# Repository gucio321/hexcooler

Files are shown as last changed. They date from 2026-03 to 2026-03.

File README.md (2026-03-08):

# Intro
HexCooler is a laptop cooling stand project designed with a hexagonal pattern.

# BOM
> [!note]
> The BOM is work in progress. It is possible that some materials are missing right now.

> [!important]
> I assume you have basic knowledge about 3D printing as well as access to a 3D printer.
> Also, I assume you have basic knowledge about soldering and you have access to a soldering setup.

> [!tip]
> I don't give you links as I assume you can find the best offer yourself :smile:

> [!tip]
> I did most purchases in PLN, so USD prices are approximate.

| Item | Quantity | Price [PLN] | Price [USD] | Notes |
|---|---|---|---|---|
| Filaments (PLA)  | 2 * 1 kg (one black and one red - pick whatever colors you want) | 85 | 24 |  |
| Be Quiet! Pure Wings 3 140mm 3-Pin black | 1 | 50 | 14 |  |
| Hex Cooler V1 PCB on [JLCPCB](https://jlcpcb.com/) (see [project file](./hexcooler_v1.epro)) | 2 assembled + 3 printed boards | 73.20 | 20 | This is what I paid for USD in my bank. In reality, it was a bit cheaper on JLCPCB (as some of those USD left on my currency account) |
| **Total** |  | 208.20 | 58 |  |

> [!note]
> I also used some universal pins to connect my fan to the PCB. You can alternatively use goldpins or (not recommended) cut the plug and solder the fan wires directly to the PCB.

> [!note]
> As this is V1 I ordered only 2 assembled boards from JLCPCB. If you are going to build multiple coolers, it is theoretically possible to cut costs by ordering more assembled boards.
> Also, if you have advanced soldering skills, you can order unassembled boards + components (much cheaper) and solder them yourself.
> Also I didn't print all the filament I bought - you can save some money there.

# How to build

1. Chose a PCB version (tl;dr: [v2](./hexcooler_v2.epro) is recommended) see [#PCB-versions]
1. Order all the parts from the BOM. Note that delivery time especially for PCBs may be long.
2. Install FreeCAD
3. Download this repository
4. Open `hexcooler.fcstd` in FreeCAD
5. Click on `VarSet` and adjust whatever parameters you want (e.g. fan holder size, hex dimensions, e.t.c.)
6. Export each individual part
   (PROTIP: If your printer is too small to print the whole part at once, you can set NX/NY to e.g. half, and print twice,
   but be careful to verify before printing - some frame parts are 1 tile wider so printing them twice will not work with
   printing the grid twice - you know what I mean, just count tiles and you'll see what I mean :smile:).
   One more protip: I recommend printing a small prototype first (e.g. with nx=1, ny=1) and check if junctions fit well (they should not be too loose or too ight - check JunctionTolerance var).
7. Print all the parts
8. Assemble the parts together (you can use some glue if you need but I didn't use any and it works for me)
9. Its done! GG!

## PCB versions

At this point, there are two variants of the PCB.
The first one (v1) is a really minimalistic design with only one fan connector and no mounting holes (what makes it really uncomfortable to use).
If you want this version, you should design your own BoardHandler part (as one in the project is really bad and because v2 exists I'm not going to fix it).
If you really want to use the project design, take a look at models from commit 1aaabbce1ec494832992ce61475a56b12ce3519e

V2 is a much better design imao. It includes 4 12V fan connectors and in addition 3 5V connectors for e.g. some leds (not tested yet). It also includes mounting holes which makes it that plugging the
USB cable is not a nightmare anymore. I highly recommend using this version, especially that it is not more expensive than v1 (as the price of PCB on JLCPCB is mostly determined by assembly costs and not size of the PCB).

# Status
WIP :smile:

**04.11.2025** The first project iteration has just been printed. It has some minor issues (e.g. one missing junction) which however has already been fixed.
I also experienced a skill issue (while exporting the bottom part I didn't export mirrors)
**18.01.2026** The project has been printed almost entirely and is under use. It is missing some minor parts (e.g. the stand - comming soon) but geneerally looks good and is usable.

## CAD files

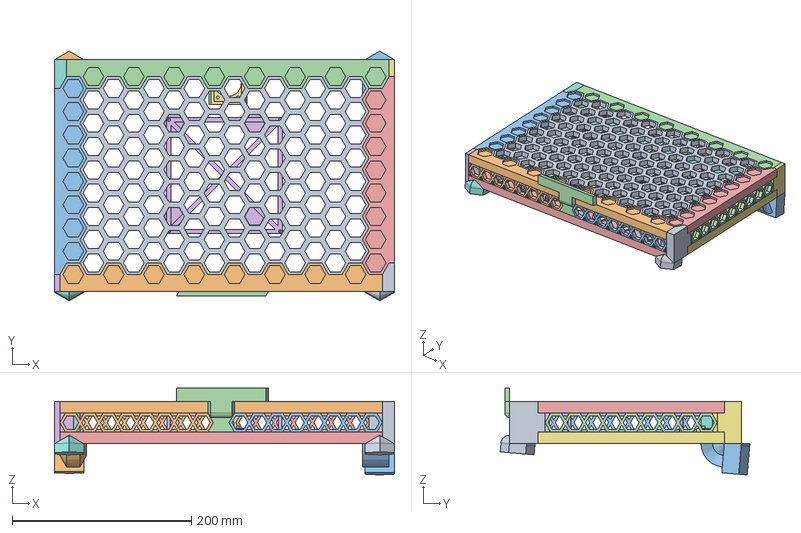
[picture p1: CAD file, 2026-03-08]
hexcooler.FCStd
379.8 x 278.8 x 97.1 mm
Grid
FrameBot
FrameLeft
FrameTop
FrameRight
StemLB
StemRT
StemLT
StemRB
InteriorMaskFrontLeft
InteriorMaskFrontRight
FrontPanel
DFrameBot (Mirror #1)
DGrid (Mirror #2)
DFrameRight (Mirror #3)
DFrameTop (Mirror #4)
DFrameLeft (Mirror #5)
InteriorMaskBackLeft (Mirror #6)
InteriorSideLeft
InteriorSideRight (Mirror #8)
InteriorMaskBackRight (Mirror #8)
FanHolder
BoardHolder
StandLB
StandRB
StandLT
StandRT

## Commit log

2025-10-26 parametrize junction
    [top.FCStd]
2025-10-26 rework to use MultipleTransform instead of drafts
    [top.FCStd]
2025-10-27 top: fix tip; add Internal section in VarSet
    [top.FCStd]
2025-10-27 top: add mjunction on left side
    [top.FCStd]
2025-10-27 top: add hex that is placed parametrically on the right edge
    [top.FCStd]
2025-10-27 top: add rside fjunction
    [top.FCStd]
2025-10-27 top: add mjunctions on top
    [top.FCStd]
2025-10-27 top: add bottom junctions
    [top.FCStd]
2025-10-27 top: add Info section in varset
    [top.FCStd]
2025-10-27 add bottom frame part
    [top.FCStd]
2025-10-27 top: add all the frames
    [top.FCStd]
2025-10-27 add more parameters and adjust NX/NY values
    [top.FCStd]
2025-10-27 add missing junctions left frame and fix bug in top edge of grid
    [top.FCStd]
2025-10-28 add missing junctions on all panels
    [top.FCStd]
2025-10-28 rename top => hexcooler
    as this will not contain only the top layer
    [hexcooler.FCStd]
2025-10-28 fix RFrame junctions; add first corner
    [hexcooler.FCStd]
2025-10-28 once again fix top frame engraving (redesign sketch)
    [hexcooler.FCStd]
2025-10-28 add frame extrusion
    [hexcooler.FCStd]
2025-10-28 once again fix top frame engraving (its cursed...) and add stem clone
    [hexcooler.FCStd]
2025-10-29 finally fix top frame engraving; add lt stem
    [hexcooler.FCStd]
2025-10-29 right frame: fix missing junction
    [hexcooler.FCStd]
2025-10-29 add stemRB placement
    [hexcooler.FCStd]
2025-10-29 correct LTStem to work with downscaling hex D/H
    [hexcooler.FCStd]
2025-10-30 botframe: add junction for the stem
    [hexcooler.FCStd]
2025-10-30 stemlb: add mjunction
    [hexcooler.FCStd]
2025-10-30 stemrt: fix positioning and rotation
    [hexcooler.FCStd]
2025-10-30 lframe: fix support
    [hexcooler.FCStd]
2025-10-30 rframe: fix support
    [hexcooler.FCStd]
2025-10-30 rtstem: fix y positioning
    [hexcooler.FCStd]
2025-10-30 topframe: fix support visibility
    [hexcooler.FCStd]
2025-10-30 lbstem: add support
    [hexcooler.FCStd]
2025-10-30 lbstem: make it more fancy
    [hexcooler.FCStd]
2025-10-30 bframe: add experimental junction hole
    [hexcooler.FCStd]
2025-10-31 bot support fjunction: fix constraintness and sizing
    [hexcooler.FCStd]
2025-10-31 rframe: fix engraving placement
    [hexcooler.FCStd]
2025-10-31 begin work on front hex mask (interior Hex)
    [hexcooler.FCStd]
2025-10-31 stemlt: add extrusion; finish front mask dimesioning
    [hexcooler.FCStd]
2025-10-31 add front panel
    [hexcooler.FCStd]
2025-10-31 fix front panel placement
    [hexcooler.FCStd]
2025-10-31 mirror fpanel junction
    [hexcooler.FCStd]
2025-10-31 ltstem: add fjunction
    [hexcooler.FCStd]
2025-10-31 frame: add stem junctions
    [hexcooler.FCStd]
2025-10-31 front panel: mirror junction
    [hexcooler.FCStd]
2025-10-31 add laptop holder extrusion
    [hexcooler.FCStd]
2025-10-31 some updates and fixes
    [hexcooler.FCStd]
2025-11-01 topframe: add junction
    [hexcooler.FCStd]
2025-11-01 add engraved vendor text
    [hexcooler.FCStd]
2025-11-02 add a local CS in the middle of the Grid
    [hexcooler.FCStd]
2025-11-02 mirror some parts; add colors
    [hexcooler.FCStd]
2025-11-02 mirror more parts
    [hexcooler.FCStd]
2025-11-02 right frame: add bot junction
    [hexcooler.FCStd]
2025-11-02 place a side interior hex
    [hexcooler.FCStd]
2025-11-02 add side masks
    [hexcooler.FCStd]
2025-11-02 fix one minotr placement thing
    [hexcooler.FCStd]
2025-11-02 fix InterDistance calculation
    [hexcooler.FCStd]
2025-11-02 lbstem: add mirrored junction
    [hexcooler.FCStd]
2025-11-02 mirror top in ltstem
    [hexcooler.FCStd]
2025-11-02 fix back mask placement
    [hexcooler.FCStd]
2025-11-02 added some info vars
    [hexcooler.FCStd]
2025-11-02 add corner rounding
    [hexcooler.FCStd]
2025-11-03 hexcooler: fix broken side hex N calculation
    [hexcooler.FCStd]
2025-11-04 add missing junction on the right frame
    [hexcooler.FCStd]
2025-11-11 bugfix of rside junctions
    [hexcooler.FCStd]
2025-11-12 hexcooler/grid: fix rsid junctions
    [hexcooler.FCStd]
2025-11-12 update fanmount sizing
    [hexcooler.FCStd]
2025-11-12 fix info property naming
    [hexcooler.FCStd]
2025-11-12 evil math
    [hexcooler.FCStd]
2025-11-19 add stem junctions
    [hexcooler.FCStd]
2025-11-21 fix something broken
    [hexcooler.FCStd]
2025-11-23 fix fan holder positioning and ajdust parameters values
    [hexcooler.FCStd]
2025-11-24 fix stem fjunctions
    [hexcooler.FCStd]
2025-11-28 add latest changes
    [hexcooler.FCStd]
2025-12-04 hexcooler: add board holder and correct minorparameters
    [hexcooler.FCStd]
2026-01-18 readme: add bom
2026-01-18 add epro board project
2026-01-20 remove old stand; add new one's prototype
    also change FrontPanel's thickness
    [hexcooler.FCStd]
2026-01-22 add stand
    [hexcooler.FCStd]
2026-03-08 3d model: add support for Hexcooler v2.0.0 PRO board
    [hexcooler.FCStd]
2026-03-08 readme: explain board versions
